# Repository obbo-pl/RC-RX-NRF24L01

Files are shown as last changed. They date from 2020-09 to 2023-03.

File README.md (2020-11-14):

# RC-RX-NRF24L01
RC receiver with NRF24L01 module and compatible with the CABELL protocol

##### Main features:

- dimensions: 50.0 * 22.9 * 12.2mm (without case),
- weight: approx. 9g (without case),
- 2.4GHz NRF24L01 G-24 module,
- communication protocol compatible with CABELL v3,
- 8 channels,
- supply voltage 4.0V - 6.2V,
- serial port and I2C for telemetry,
- parameter configuration via serial port (9600bps),
- output signal levels: 5V,

For more information: [www.obbo.pl](https://obbo.pl/rc-rx-nrf24l01)

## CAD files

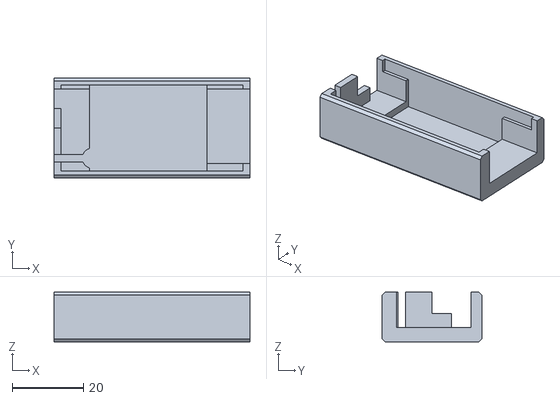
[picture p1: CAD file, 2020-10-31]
case.stl
55.0 x 28.0 x 14.0

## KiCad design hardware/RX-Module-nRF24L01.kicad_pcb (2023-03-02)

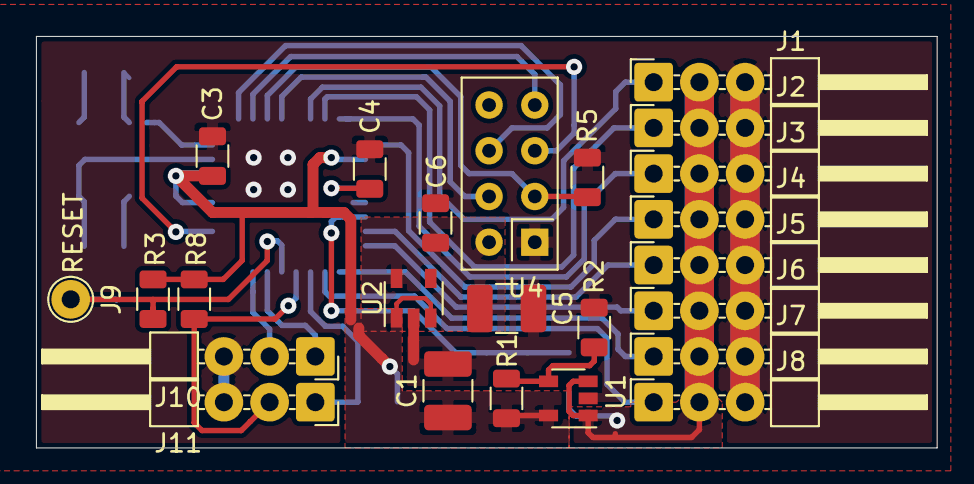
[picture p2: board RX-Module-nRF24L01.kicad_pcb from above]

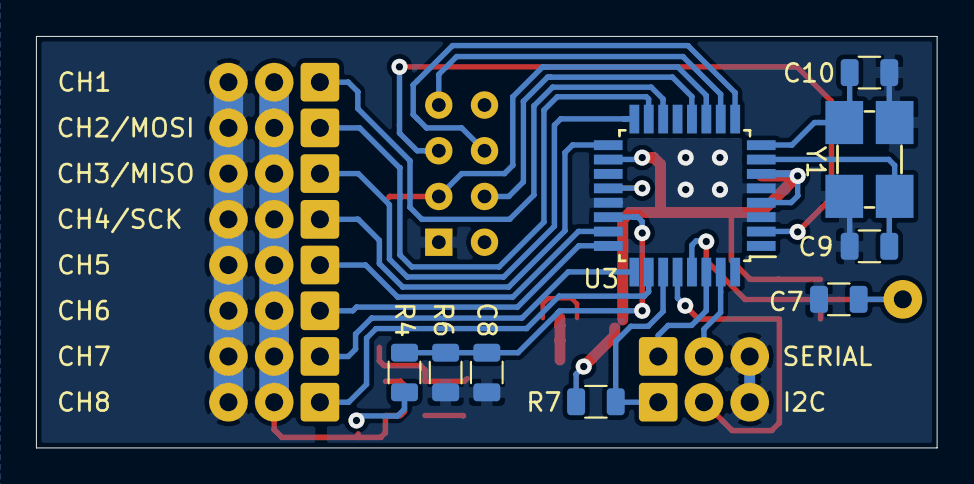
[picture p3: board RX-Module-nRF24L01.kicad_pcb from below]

Board: 2 copper layers, 50.0 x 22.9 mm, 33 parts (9 on the bottom side), 27 nets.

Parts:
C1, C5: 10u; C_1210_3225Metric_Pad1.42x2.65mm_HandSolder
C3, C4, C6, C7, C8: 100n; C_0805K
C9, C10: 18p; C_0805K
J1, J2, J3, J4, J5, J6, J7, J8, J10, J11: Conn_01x03; PinHeader_3x01_P2.54mm_Horizontal
J9: Conn_01x01; Pin_D1.0mm_L10.0mm_LooseFit
R1: 68k*; R_0805K
R2: 22k; R_0805K
R3, R5, R6: 10k; R_0805K
R4: 47k*; R_0805K
R7, R8: 3k3; R_0805K
U1: TPS73601DBV; SOT-23-5
U2: TPS73633DBV; SOT-23-5
U3: ATmega328-AU; TQFP-32_7x7mm_P0.8mm
U4: NRF24L01_Breakout; nRF24L01-GT24_Breakout_PinHeader_2x04
Y1: 16MHz; Crystal_SMD_5032-4Pin_5.0x3.2mm_HandSoldering

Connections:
+3V3: C5.1, C6.1, U2.5, U4.2
+5V: C1.1, C3.1, R1.1, R3.1, R7.1, R8.1, U1.5, U2.1, U2.3, U3.4, U3.6, U3.18
+BATT: J1.2, J2.2, J3.2, J4.2, J5.2, J6.2, J7.2, J8.2, R4.1, U1.1, U1.3
/CE: R5.1, U3.11, U4.3
/CH1: J1.1, U3.14
/CH5: J5.1, U3.23
/CH6: J6.1, U3.24
/CH7: J7.1, U3.25
/CH8: J8.1, U3.26
/MISO: U3.10, U4.7
/MISO_CH3: J3.1, U3.16
/MOSI: U3.9, U4.6
/MOSI_CH2: J2.1, U3.15
/NRF_CSN: U3.12, U4.4
/RESET: C7.1, J9.1, R3.2, U3.29
/Rx: J10.1, U3.30
/SCK: U3.2, U4.5
/SCK_CH4: J4.1, U3.17
/SCL: J11.2, R8.2, U3.28
/SDA: J11.1, R7.2, U3.27
/Tx: J10.2, U3.31
/VBAT: C8.1, R4.2, R6.1, U3.22
/xtl1: C9.1, U3.7, Y1.1
/xtl2: C10.2, U3.8, Y1.3
GND: C1.2, C3.2, C4.2, C5.2, C6.2, C7.2, C8.2, C9.2, C10.1, J1.3, J2.3, J3.3, J4.3, J5.3, J6.3, J7.3, J8.3, J10.3, J11.3, R2.2, R5.2, R6.2, U1.2, U2.2, U3.3, U3.5, U3.21, U4.1, Y1.2, Y1.4
unnamed: C4.1, U3.20
unnamed: R1.2, R2.1, U1.4

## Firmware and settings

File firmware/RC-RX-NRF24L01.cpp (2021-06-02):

/*
 * RC_RX_NRF24L01.cpp
 *
 * Created: 2020-05-10 00:05:03
 * Atmel Studio 6 (Version: 6.2.1563 - Service Pack 2)
 * AVR/GNU C Compiler : 4.8.1
 *  Author: Krzysztof Markiewicz
 *  www.obbo.pl
 *
 * This program is distributed under the terms of the GNU General Public License
 */ 


#include <avr/io.h>
#include <avr/eeprom.h>
#include <avr/interrupt.h>
#include <avr/pgmspace.h>
#include <util/delay.h>
#include "macro.h"
#include "config.h"
#include "tx_def.h"
#include "led.h"
#include "usart.h"
#include "cbuffer.h"
#include "adconversion.h"
#include "servo.h"
#include "spi.h"
#include "nrf24l01_spi.h"
#include "cabell_nrf224l01.h"
#include "uptime.h"
#include "terminal.h"
#include "terminal_commands.h"
#include "lowpass_filter.h"
#include "throttle.h"
#include "failsafe.h"


#define VERSION_MAJOR				"1"
#define VERSION_MINOR				"2"
#define DEVICE_INFO_SIZE			64
const char DEVICE_INFO[DEVICE_INFO_SIZE]	PROGMEM = "RC-RX-NRF24L01 " VERSION_MAJOR "." VERSION_MINOR " (build: " __DATE__ " " __TIME__ ")\n\r";

#define MAIN_STATUS_UPDATE_DELAY		1000		// update every 0.1sec
#define PACKET_LIFETIME				28

//#define MAIN_CHECK_SERVO_PORT 

#define MAIN_THROTTLE_PROTECTION
#define MAIN_THROTTLE_CHANNEL			THROTTLE

uint8_t EEMEM EEMEM_battery_divider = 40;

char EEMEM main_message_001[] = "Initializing\n\r";
char EEMEM main_message_002[] = "NRF24L01 detected\n\r";
char EEMEM main_message_003[] = "NRF24L01 not detected\n\r";

uint16_t servo_channels_value[CONFIG_CHANNELS_MAX_COUNT];
CircularBuffer_t cbuffer;
DCTERMINAL_t terminal;
const char *device_info;
uint8_t battery_voltage;
uint8_t battery_divider;
UpTime uptime;
ServoChain servos;
LPFu16_t filter_adc;


void main_ReadBatteryVoltage(uint8_t *voltage);
void main_SaveSetup(void);
void main_ReadSetup(void);
void main_InitServos(ServoChain *servos);
void main_InitRadioTimer(void);
void main_InitServoTimer(void);
void main_SetStatusLed(LED *led, uint8_t *protocol, uint8_t *failsafe);
#ifdef SERVO_CHAIN_STROBE_BY_16BIT_0us5_TIMER
void main_StartServoTimer(uint16_t length);
#else
void main_StartServoTimer(uint8_t length);
#endif

enum MAIN_PHASE {
	PHASE_EXCHANGE_PACKET,
	PHASE_UPDATE_SERVO_CHANNEL_PULSE,
	PHASE_EMIT_TELEMETRY,
	PHASE_CHANNEL_SWITCH,
	PHASE_UPDATE_STATE,
	PHASE_FINISH
};



int main(void)
{
#ifdef CONFIG_CH1
	Servo servo_ch1(PORT_REG_IO(CONFIG_CH1));
	servos.bind(&servo_ch1, 1);
#endif
#ifdef CONFIG_CH2
	Servo servo_ch2(PORT_REG_IO(CONFIG_CH2));
	servos.bind(&servo_ch2, 2);
#endif
#ifdef CONFIG_CH3
	Servo servo_ch3(PORT_REG_IO(CONFIG_CH3));
	servos.bind(&servo_ch3, 3);
#endif
#ifdef CONFIG_CH4
	Servo servo_ch4(PORT_REG_IO(CONFIG_CH4));
	servos.bind(&servo_ch4, 4);
#endif
#ifdef CONFIG_CH5
	Servo servo_ch5(PORT_REG_IO(CONFIG_CH5));
	servos.bind(&servo_ch5, 5);
#endif
#ifdef CONFIG_CH6
	Servo servo_ch6(PORT_REG_IO(CONFIG_CH6));
	servos.bind(&servo_ch6, 6);
#endif
#ifdef CONFIG_CH7
	Servo servo_ch7(PORT_REG_IO(CONFIG_CH7));
	servos.bind(&servo_ch7, 7);
#endif
#ifdef CONFIG_CH8
	Servo servo_ch8(PORT_REG_IO(CONFIG_CH8));
	servos.bind(&servo_ch8, 8);
#endif
	servos.attach();
	
	SET_PIN_AS_IN(CONFIG_BIND_BUTTON);
	SET_PIN_PULLUP(CONFIG_BIND_BUTTON);
	bool service_mode = true;
	for (uint8_t i = 0; i < 100; i++) {
		_delay_ms(1);
 		if (READ_PIN(CONFIG_BIND_BUTTON)) {
			service_mode = false;
			break;
		}
	}
 	LED led_status(PORT_REG_O(CONFIG_STATUS_LED));
	if (service_mode) {
		led_status.init();
		for (uint8_t i = 0; i < 21; i++) {
			led_status.setLed(true, false);
			led_status.update();
			_delay_ms(100);
			led_status.setLed(false, false);
			led_status.update();
			_delay_ms(100);
		}
	}
			
	device_info = DEVICE_INFO;
	usart_Init();
	cbuffer_Init(&cbuffer);
	terminal_Init(&terminal, &cbuffer);
		
 	terminal_SendNL(&cbuffer, true);
 	terminal_PrintPM(&cbuffer, device_info, true);
 	terminal_PrintEE(&cbuffer, main_message_001, true);
	main_InitRadioTimer();
	main_InitServoTimer();

	main_ReadSetup();
	lpfilter_Set(&filter_adc, 3);
	lpfilter_Fill(&filter_adc, 0xFF);
	adc_Init(glue2(ADCONVERSION_MUX_ADC,CONFIG_VBAT_MUX_IN));
	
	Throttle throttle(MAIN_THROTTLE_CHANNEL, &uptime);
	throttle.bindTerminal(&cbuffer);
	Failsafe failsafe;
	failsafe.init(&uptime);
	SPI spi;
	NRF24L01 radio(&spi, PORT_REG_O(CONFIG_NRF_CE), PORT_REG_O(CONFIG_NRF_CSN));
	CABELL protocol(&radio, &uptime, service_mode, servo_channels_value);
	protocol.bindTerminal(&cbuffer);
	terminal_commands_receiver_Init(&protocol, servo_channels_value, device_info, &battery_voltage, &battery_divider, &radio);
	terminal_commands_throttle_Init(&throttle);
	terminal_commands_failsafe_Init(&failsafe);
	bool enable_servo_pulses = false;

	protocol.readSetup();
	
	uint8_t bind_button = 1;
	if (service_mode) bind_button = READ_PIN(CONFIG_BIND_BUTTON);
	protocol.checkBindRequest(bind_button);
	failsafe.check(servo_channels_value,
		       &enable_servo_pulses,
		       protocol.cabell.timer.last_good_packet,
		       testbit(protocol.cabell.state.protocol, CABELL_STATE_INITIAL_GOOD_PACKET));
	servos.setValues(servo_channels_value);
	servos.enablePulses(enable_servo_pulses);

	sei();
	servos.interruptHandler(main_StartServoTimer);
	_delay_ms(100);

	if (protocol.init()) {
		terminal_PrintEE(&cbuffer, main_message_002, true);
		protocol.initRadio();
	} else {
		terminal_PrintEE(&cbuffer, main_message_003, true);
	}
	
	uint8_t command_length;
	uint8_t main_phase = 0;

	uint32_t telemetry_emit_delay = 0;
	uint32_t packet_lifetime = 0;
	
 	uint32_t led_update_time = uptime.getTime() + MAIN_STATUS_UPDATE_DELAY;
	uint8_t state_protocol;
	uint8_t state_failsafe;
	uint8_t state_errors;
	protocol.getState(&state_protocol, &state_errors);
	failsafe.getState(&state_failsafe);
	if (service_mode) main_SetStatusLed(&led_status, &state_protocol, &state_failsafe);
	
	while (true) {
		switch (main_phase) {
			case PHASE_EXCHANGE_PACKET:
				packet_lifetime = uptime.getTime();
				if (protocol.exchangePacket(&telemetry_emit_delay)) {
					packet_lifetime += PACKET_LIFETIME;
					if (telemetry_emit_delay) packet_lifetime += CABELL_TELEMETRY_EXTEND_INTERVAL;
					main_phase = PHASE_UPDATE_SERVO_CHANNEL_PULSE;
				} else {
					main_phase = PHASE_FINISH;
				}
				break;
			case PHASE_UPDATE_SERVO_CHANNEL_PULSE:
				failsafe.check(servo_channels_value, 
					       &enable_servo_pulses, 
					       protocol.cabell.timer.last_good_packet, 
					       testbit(protocol.cabell.state.protocol, CABELL_STATE_INITIAL_GOOD_PACKET));
#ifdef MAIN_THROTTLE_PROTECTION
				throttle.check(servo_channels_value, 
					       protocol.cabell.timer.last_good_packet, 
					       testbit(protocol.cabell.state.protocol, CABELL_STATE_INITIAL_GOOD_PACKET),
					       testbit(failsafe.state, FAILSAFE_STATE_ACTIVE));
#endif
				servos.setValues(servo_channels_value);				
				servos.enablePulses(enable_servo_pulses);
				if (service_mode) {
					if (!READ_PIN(CONFIG_BIND_BUTTON)) failsafe.saveValues(servo_channels_value);			
				}
				main_phase++;
				break;
			case PHASE_EMIT_TELEMETRY:
				if (uptime.getTime() >= telemetry_emit_delay) main_phase++;
				break;
			case PHASE_CHANNEL_SWITCH:
				protocol.setNextRadioChannel();
				main_phase++; 
				break;
			case PHASE_UPDATE_STATE:
				main_ReadBatteryVoltage(&battery_voltage);
				protocol.setTelemetryFrame(battery_voltage, 0);
				main_phase++;
				break;
			case PHASE_FINISH:  
				if (protocol.cabell.state.request) {
					if (testbit(protocol.cabell.state.request, CABELL_STATE_REQUEST_FAILSAFE_DEFAULT)) {
						clrbit(protocol.cabell.state.request, CABELL_STATE_REQUEST_FAILSAFE_DEFAULT);
						failsafe.setDefaultValues();
					}
					if (testbit(protocol.cabell.state.request, CABELL_STATE_REQUEST_FAILSAFE_NO_PULSES)) {
						clrbit(protocol.cabell.state.request, CABELL_STATE_REQUEST_FAILSAFE_NO_PULSES);
						failsafe.savePulseMode(false);
					}
					if (testbit(protocol.cabell.state.request, CABELL_STATE_REQUEST_FAILSAFE_ERASE)) {
						clrbit(protocol.cabell.state.request, CABELL_STATE_REQUEST_FAILSAFE_ERASE);
						failsafe.eraseValues();
					}
					if (testbit(protocol.cabell.state.request, CABELL_STATE_REQUEST_FAILSAFE_SAVE)) {
						clrbit(protocol.cabell.state.request, CABELL_STATE_REQUEST_FAILSAFE_SAVE);
						failsafe.saveValues(servo_channels_value);
					}
				} else failsafe.setConfigurationEnabled();
				if (service_mode) {
					protocol.getState(&state_protocol, &state_errors);
					failsafe.getState(&state_failsafe);
					if (led_update_time < uptime.getTime()) {
						main_SetStatusLed(&led_status, &state_protocol, &state_failsafe);
						led_status.update();
						led_update_time = uptime.getTime() + MAIN_STATUS_UPDATE_DELAY;
					}
				}
				terminal_SendOutBuffer(&cbuffer);
				if (terminal.change_to_write) {
					terminal.change_to_write = false;
					main_SaveSetup();
				}
  				if (terminal.input_is_full) terminal_DropInputBuffer(&terminal);
 				if (terminal_FindNewLine(&terminal, &command_length)) terminal_ParseCommand(&terminal, command_length);
				
				if (uptime.getTime() >= packet_lifetime) main_phase = PHASE_EXCHANGE_PACKET;
				break;
		}
	}
}

ISR(USART_RX_vect)
{
	terminal_InterruptHandler(&terminal);
}

ISR(TIMER0_COMPA_vect)
{
	// tic every 100us
	// counter overload occurs after 4,97 days
	uptime.interruptHandler();
}

#ifdef SERVO_CHAIN_STROBE_BY_16BIT_0us5_TIMER
ISR(TIMER1_COMPA_vect)
{
	// stop timer
	TCCR1B &= ~((1 << CS12) | (1 << CS11) | (1 << CS10));
	servos.interruptHandler(main_StartServoTimer);
}

#else
ISR(TIMER2_COMPA_vect)
{
	// stop timer
	TCCR2B &= ~((1 << CS22) | (1 << CS21) | (1 << CS20));
	servos.interruptHandler(main_StartServoTimer);
}
#endif

void main_InitRadioTimer(void)
{
	TCCR0A = (1 << WGM01);
	TCCR0B = (1 << FOC0A) | (1 << CS01);
	OCR0A = 199;
	TIMSK0 = (1 << OCIE0A);
}

#ifdef SERVO_CHAIN_STROBE_BY_16BIT_0us5_TIMER
void main_InitServoTimer(void)
{
	TCCR1A = 0x00;
	TCCR1B = (1 << WGM12);
	TCCR1C = (1 << FOC1A);
	TIMSK1 = (1 << OCIE1A);
}

void main_StartServoTimer(uint16_t length)
{
	OCR1A = length;
	TCCR1B |= (1 << CS11);
}

#else
void main_InitServoTimer(void)
{
	TCCR2A = (1 << WGM21);
	TCCR2B = (1 << FOC2A);
	TIMSK2 = (1 << OCIE2A);
}

void main_StartServoTimer(uint8_t length)
{
	OCR2A = length;
	TCCR2B |= (1 << CS22);
}
#endif

void main_ReadBatteryVoltage(uint8_t *voltage)
{
	uint8_t bat;
	if (adc_Read(&bat)) {
		*voltage = lpfilter_Filter(&filter_adc, bat);
	}
}

void main_SetStatusLed(LED *led, uint8_t *protocol, uint8_t *failsafe)
{
	if (testbit(*failsafe, FAILSAFE_STATE_ACTIVE)) {
		led->setLed(true, false);
	} else if (testbit(*protocol, CABELL_STATE_REBOOT_PENDING)) {
		led->setTimers(20, 10);
		led->setLed(true, true);
	} else if (testbit(*protocol, CABELL_STATE_BIND_MODE)) {
		led->setTimers(20, 2);
		led->setLed(true, true);
	} else if (!(testbit(*protocol, CABELL_STATE_IN_SYNC))) {
		led->setTimers(3, 1);
		led->setLed(true, true);
	} else {
		led->setLed(false, false);
	}
}

void main_SaveSetup(void)
{
	eeprom_write_byte(&EEMEM_battery_divider, battery_divider);
}

void main_ReadSetup(void)
{
	battery_divider = eeprom_read_byte(&EEMEM_battery_divider);
}

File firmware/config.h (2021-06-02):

/*
 * config.h
 *
 * Created: 2020-05-10 23:40:32
 * Atmel Studio 6 (Version: 6.2.1563 - Service Pack 2)
 * AVR/GNU C Compiler : 4.8.1
 *  Author: Krzysztof Markiewicz
 *  www.obbo.pl
 *
 * This program is distributed under the terms of the GNU General Public License
 */ 


#ifndef CONFIG_H_
#define CONFIG_H_

// PPM signal
#define CONFIG_CHANNELS_MAX_COUNT	16
#define CONFIG_CHANNEL_MIN_VALUE	1000
#define CONFIG_CHANNEL_MID_VALUE	1500
#define CONFIG_CHANNEL_MAX_VALUE	2000

// Servo signals
#define CONFIG_CH1			B,2
#define CONFIG_CH2			B,3
#define CONFIG_CH3			B,4
#define CONFIG_CH4			B,5
#define CONFIG_CH5			C,0
#define CONFIG_CH6			C,1
#define CONFIG_CH7			C,2
#define CONFIG_CH8			C,3

// Servo channel order
#define	ATER

// SPI signals
#define CONFIG_NRF_MOSI			D,5
#define CONFIG_NRF_MISO			D,6
#define CONFIG_NRF_SCK			D,4

// NRF24L01 radio signals
#define CONFIG_NRF_CSN			B,0
#define CONFIG_NRF_CE			D,7

// Battery voltage measure
#define CONFIG_VBAT_MUX_IN		7

// check service mode
#define CONFIG_TWI_SDA			C,4
#define CONFIG_TWI_SCL			C,5

// Bind button
#define CONFIG_BIND_BUTTON		CONFIG_TWI_SDA

// LED
#define CONFIG_STATUS_LED		CONFIG_TWI_SCL


// Terminal command set
#define TERMINAL_CABELL_FULL_STATISTICS
#define TERMINAL_NRF24L01_RADIO_STATE



#endif /* CONFIG_H_ */

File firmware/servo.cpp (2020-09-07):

/*
 * servo.cpp
 *
 * Created: 2020-05-12 21:53:08
 * Atmel Studio 6 (Version: 6.2.1563 - Service Pack 2)
 * AVR/GNU C Compiler : 4.8.1
 *  Author: Krzysztof Markiewicz
 *  www.obbo.pl
 *
 * This program is distributed under the terms of the GNU General Public License
 */ 

#include <stdlib.h>
#include <util/delay.h>
#include "servo.h"
#include "macro.h"


#define SERVO_CHECK_PORT_DELAY_ms		(50)
#define SERVO_CHAIN_CHANNEL_DELAY		(SERVO_MAX_PULSE_PERIOD / SERVO_CHAIN_MAX_LENGTH)
#define SERVO_CHAIN_PULSE_CORRECTION		(9)
#define SERVO_CHAIN_MINIMUM_TIMER_VALUE		(4)


#ifndef SERVO_CHAIN_STROBE_BY_16BIT_0us5_TIMER
#if SERVO_MIN_PULSE_WIDTH < 1000
#error "For an 8-bit strobe timer, the minimum pulse length must not be less than 1000"
#endif
#if SERVO_MAX_PULSE_WIDTH > 2000
#error "For an 8-bit strobe timer, the maximum pulse length cannot be greater than 2000"
#endif
#if SERVO_CHAIN_MINIMUM_TIMER_VALUE > 5
#error "For an 8-bit strobe timer, the minimum timer value cannot be greater than 5"
#endif
#endif


// Class Servo
Servo::Servo(uint8_t volatile *regpin, uint8_t volatile *regddr, uint8_t volatile *regport, uint8_t pin)
{
	servo.out.regpin = regpin;
	servo.out.regddr = regddr;
	servo.out.regport = regport;
	servo.out.pin = pin;
}

void Servo::attach(void)
{
	clrbit(*(servo.out.regport), servo.out.pin);
	setbit(*(servo.out.regddr), servo.out.pin);
}

void Servo::detach(void)
{
	clrbit(*(servo.out.regddr), servo.out.pin);
}

void Servo::startPulse(void)
{
	setbit(*(servo.out.regport), servo.out.pin);
}

void Servo::stopPulse(void)
{
	clrbit(*(servo.out.regport), servo.out.pin);
}

bool Servo::checkPort(void)
{
	bool result = true;
	clrbit(*(servo.out.regddr), servo.out.pin);
	setbit(*(servo.out.regport), servo.out.pin);
	_delay_ms(SERVO_CHECK_PORT_DELAY_ms);
	if (!(testbit(*(servo.out.regpin), servo.out.pin))) result = false;
	return result;
}



// Class Servo_Chain
ServoChain::ServoChain(void)
{
	for (uint8_t i = 0; i < SERVO_CHAIN_MAX_LENGTH; i++) {
		servos[i] = NULL;
	}
	current_servo = 0;
	phase = SERVO_CHAIN_PULSE_BASE;
	pulses_enabled = false;
}

void ServoChain::bind(Servo *ch, uint8_t channel)
{
	channel--;
	if (channel < SERVO_CHAIN_MAX_LENGTH) {
		servos[channel] = ch;
	}
}

void ServoChain::unbind(uint8_t channel)
{
	channel--;
	if (channel < SERVO_CHAIN_MAX_LENGTH) {
		servos[channel] = NULL;
	}
}

void ServoChain::attach(void)
{
	for (uint8_t i = 0; i < SERVO_CHAIN_MAX_LENGTH; i++) {
		if (servos[i]) servos[i]->attach();
	}
}

void ServoChain::detach(void)
{
	for (uint8_t i = 0; i < SERVO_CHAIN_MAX_LENGTH; i++) {
		if (servos[i]) servos[i]->detach();
	}
}

uint8_t ServoChain::checkPort(void)
{
	uint8_t result = 0xFF;
	for (uint8_t i = 0; i < SERVO_CHAIN_MAX_LENGTH; i++) {
		if (servos[i]) {
			if (!(servos[i]->checkPort())) clrbit(result, i);
		}
	}
	return result;
}

void ServoChain::enablePulses(bool enable)
{
	pulses_enabled = enable;
}

void ServoChain::setValues(uint16_t *values)
{
	for (uint8_t i = 0; i < SERVO_CHAIN_MAX_LENGTH; i++) {
		uint16_t temp_value = values[i];
		if (temp_value < SERVO_MIN_PULSE_WIDTH) temp_value = SERVO_MIN_PULSE_WIDTH;
		else if (temp_value > SERVO_MAX_PULSE_WIDTH) temp_value = SERVO_MAX_PULSE_WIDTH;
#ifdef SERVO_CHAIN_STROBE_BY_16BIT_0us5_TIMER
		pulse_length[i] =  2 * (temp_value - SERVO_CHAIN_PULSE_CORRECTION);
#else
		pulse_length[i] = (uint8_t)((temp_value - SERVO_MIN_PULSE_WIDTH) / 4);
#endif
	}
}

#ifdef SERVO_CHAIN_STROBE_BY_16BIT_0us5_TIMER
void ServoChain::interruptHandler(void (*start_timer_0us5)(uint16_t))
{
	switch(phase) {
		case SERVO_CHAIN_PULSE_BASE:
			phase = SERVO_CHAIN_PULSE_PAUSE;
			if (servos[current_servo]) {
				if (pulses_enabled) servos[current_servo]->startPulse();
				pause = 2 * (SERVO_CHAIN_CHANNEL_DELAY - SERVO_CHAIN_PULSE_CORRECTION) - pulse_length[current_servo];
				start_timer_0us5(pulse_length[current_servo]);
			} else {
				pause = SERVO_CHAIN_CHANNEL_DELAY - SERVO_CHAIN_PULSE_CORRECTION;
				start_timer_0us5(SERVO_CHAIN_CHANNEL_DELAY - SERVO_CHAIN_PULSE_CORRECTION);
			}
			break;
		case SERVO_CHAIN_PULSE_PAUSE:
			if (servos[current_servo]) servos[current_servo]->stopPulse();
			phase = SERVO_CHAIN_PULSE_BASE;
			nextServo();
			start_timer_0us5(pause);
			break;
	}
}

#else
void ServoChain::interruptHandler(void (*start_timer_4us)(uint8_t))
{
	switch(phase) {
		case SERVO_CHAIN_PULSE_BASE:
			phase = SERVO_CHAIN_PULSE_EXTENSION;
			if (servos[current_servo]) {
				if (pulses_enabled) servos[current_servo]->startPulse();
			}
			start_timer_4us((SERVO_MIN_PULSE_WIDTH - SERVO_CHAIN_PULSE_CORRECTION) / 4 - SERVO_CHAIN_MINIMUM_TIMER_VALUE);
			break;
		case SERVO_CHAIN_PULSE_EXTENSION:
			phase = SERVO_CHAIN_PULSE_PAUSE;
			if (servos[current_servo]) {
				pause = ((SERVO_MIN_PULSE_WIDTH / 4) - pulse_length[current_servo]) + SERVO_CHAIN_MINIMUM_TIMER_VALUE;
				start_timer_4us(pulse_length[current_servo] + SERVO_CHAIN_MINIMUM_TIMER_VALUE);
			} else {
				pause = SERVO_MIN_PULSE_WIDTH / 8 + SERVO_CHAIN_MINIMUM_TIMER_VALUE;
				start_timer_4us(SERVO_MIN_PULSE_WIDTH / 8 + SERVO_CHAIN_MINIMUM_TIMER_VALUE);
			}
			break;
		case SERVO_CHAIN_PULSE_PAUSE:
			if (servos[current_servo]) servos[current_servo]->stopPulse();
			phase = SERVO_CHAIN_PAUSE_BASE;
			nextServo();
			start_timer_4us(pause);
			break;
		case SERVO_CHAIN_PAUSE_BASE:
			phase = SERVO_CHAIN_PULSE_BASE;
			start_timer_4us((SERVO_MIN_PULSE_WIDTH - 2 * SERVO_CHAIN_PULSE_CORRECTION) / 8 - SERVO_CHAIN_MINIMUM_TIMER_VALUE);
			break;
	}
}
#endif

void ServoChain::nextServo(void)
{
	current_servo++;
	if (current_servo >= SERVO_CHAIN_MAX_LENGTH) current_servo = 0;
}

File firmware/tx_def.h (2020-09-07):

//Channel order
#ifdef AETR
	#define	AILERON  0
	#define	ELEVATOR 1
	#define	THROTTLE 2
	#define	RUDDER   3
#endif
#ifdef AERT
	#define	AILERON  0
	#define	ELEVATOR 1
	#define	THROTTLE 3
	#define	RUDDER   2
#endif
#ifdef ARET
	#define	AILERON  0
	#define	ELEVATOR 2
	#define	THROTTLE 3
	#define	RUDDER   1
#endif
#ifdef ARTE
	#define	AILERON  0
	#define	ELEVATOR 3
	#define	THROTTLE 2
	#define	RUDDER   1
#endif
#ifdef ATRE
	#define	AILERON  0
	#define	ELEVATOR 3
	#define	THROTTLE 1
	#define	RUDDER   2
#endif
#ifdef ATER
	#define	AILERON  0
	#define	ELEVATOR 2
	#define	THROTTLE 1
	#define	RUDDER   3
#endif

#ifdef EATR
	#define	AILERON  1
	#define	ELEVATOR 0
	#define	THROTTLE 2
	#define	RUDDER   3
#endif
#ifdef EART
	#define	AILERON  1
	#define	ELEVATOR 0
	#define	THROTTLE 3
	#define	RUDDER   2
#endif
#ifdef ERAT
	#define	AILERON  2
	#define	ELEVATOR 0
	#define	THROTTLE 3
	#define	RUDDER   1
#endif
#ifdef ERTA
	#define	AILERON  3
	#define	ELEVATOR 0
	#define	THROTTLE 2
	#define	RUDDER   1
#endif
#ifdef ETRA
	#define	AILERON  3
	#define	ELEVATOR 0
	#define	THROTTLE 1
	#define	RUDDER   2
#endif
#ifdef ETAR
	#define	AILERON  2
	#define	ELEVATOR 0
	#define	THROTTLE 1
	#define	RUDDER   3
#endif

#ifdef TEAR
	#define	AILERON  2
	#define	ELEVATOR 1
	#define	THROTTLE 0
	#define	RUDDER   3
#endif
#ifdef TERA
	#define	AILERON  3
	#define	ELEVATOR 1
	#define	THROTTLE 0
	#define	RUDDER   2
#endif
#ifdef TREA
	#define	AILERON  3
	#define	ELEVATOR 2
	#define	THROTTLE 0
	#define	RUDDER   1
#endif
#ifdef TRAE
	#define	AILERON  2
	#define	ELEVATOR 3
	#define	THROTTLE 0
	#define	RUDDER   1
#endif
#ifdef TARE
	#define	AILERON  1
	#define	ELEVATOR 3
	#define	THROTTLE 0
	#define	RUDDER   2
#endif
#ifdef TAER
	#define	AILERON  1
	#define	ELEVATOR 2
	#define	THROTTLE 0
	#define	RUDDER   3
#endif

#ifdef RETA
	#define	AILERON  3
	#define	ELEVATOR 1
	#define	THROTTLE 2
	#define	RUDDER   0
#endif
#ifdef REAT
	#define	AILERON  2
	#define	ELEVATOR 1
	#define	THROTTLE 3
	#define	RUDDER   0
#endif
#ifdef RAET
	#define	AILERON  1
	#define	ELEVATOR 2
	#define	THROTTLE 3
	#define	RUDDER   0
#endif
#ifdef RATE
	#define	AILERON  1
	#define	ELEVATOR 3
	#define	THROTTLE 2
	#define	RUDDER   0
#endif
#ifdef RTAE
	#define	AILERON  2
	#define	ELEVATOR 3
	#define	THROTTLE 1
	#define	RUDDER   0
#endif
#ifdef RTEA
	#define	AILERON  3
	#define	ELEVATOR 2
	#define	THROTTLE 1
	#define	RUDDER   0
#endif

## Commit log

2020-09-09 Failsafe pulse mode configuration
    [RC-RX-NRF24L01.cpp, failsafe.h, terminal_commands.cpp]
2020-10-31 printed case
    [case.stl]
2021-05-08 throttle disarm disable option
2021-06-02 status LED and bind button connected via I2C socket
2023-03-02 symbol update
    [RX-Module-nRF24L01.kicad_pcb, RX-Module-nRF24L01.sch]
